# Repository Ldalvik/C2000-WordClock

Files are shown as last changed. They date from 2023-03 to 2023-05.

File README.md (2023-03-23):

# TI-F2806x-WordClock
A replication of my "RGB-WordClock" on a TI-C2000 F28069M, written in bare metal C.

## Software
Since there is no official HAL for this device, this project required deep digging into data sheets. I threw together a small library that does basic things like starting/stopping interrupts, interfacing the main loop to be more arduino-like, and all the other IO related things I would need like digital in/out and muxing. The most important part was setting the SPI peripheral to work with a real-time clock, specifically the DS1302. After reading the datasheet, I was able to get the correct settings (baud-rate, polarity/phase, etc) and communicate back and forth with the RTC. I created a full library for it to work with this F2806x as well.

# Hardware

For the PCB, I used KiCAD and made a shield for the F28069. The LEDs I decided on were extremely small (about a millimeter), and a microscope was needed to place them correctly. Other components consist of the DS1302, resistors for each LED, capacitor for filtering, 6pF 32.768khz crystal, and a small coin cell battery for a few days of time keeping while unplugged.

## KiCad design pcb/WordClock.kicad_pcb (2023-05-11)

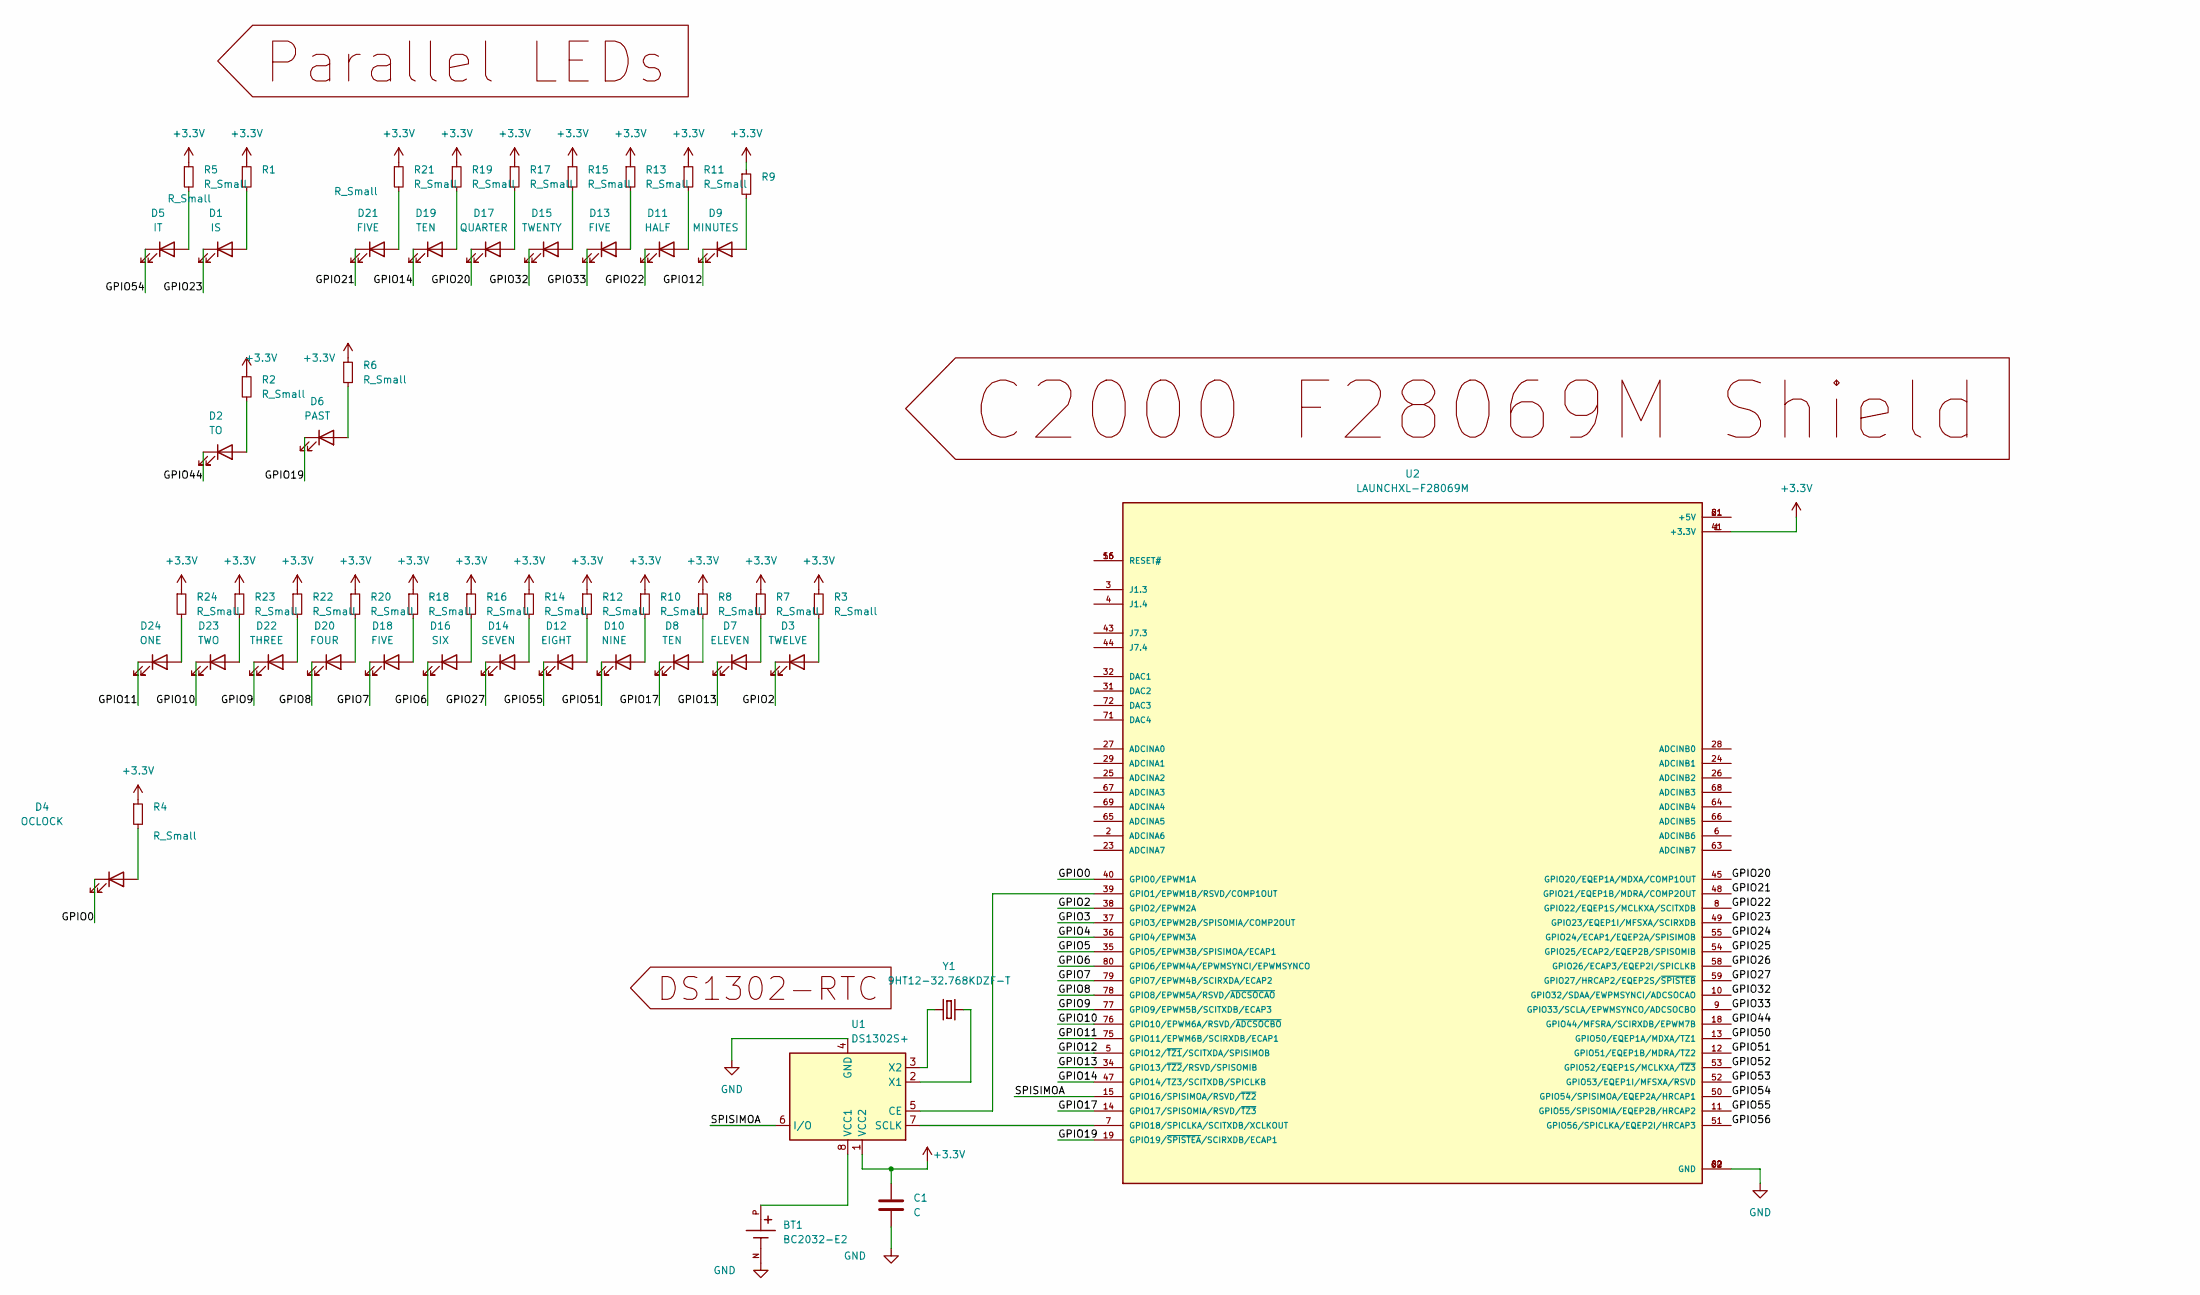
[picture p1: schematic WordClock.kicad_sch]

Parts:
BT1: BC2032-E2; MPD_BC2032-E2; PARTREV D
C1: C; C_0805_2012Metric
D1: IS; LED_0201_0603Metric_Pad0.64x0.40mm_HandSolder
D2: TO; LED_0201_0603Metric_Pad0.64x0.40mm_HandSolder
D3: TWELVE; LED_0201_0603Metric_Pad0.64x0.40mm_HandSolder
D4: OCLOCK; LED_0201_0603Metric_Pad0.64x0.40mm_HandSolder
D5: IT; LED_0201_0603Metric_Pad0.64x0.40mm_HandSolder
D6: PAST; LED_0201_0603Metric_Pad0.64x0.40mm_HandSolder
D7: ELEVEN; LED_0201_0603Metric_Pad0.64x0.40mm_HandSolder
D8, D19: TEN; LED_0201_0603Metric_Pad0.64x0.40mm_HandSolder
D9: MINUTES; LED_0201_0603Metric_Pad0.64x0.40mm_HandSolder
D10: NINE; LED_0201_0603Metric_Pad0.64x0.40mm_HandSolder
D11: HALF; LED_0201_0603Metric_Pad0.64x0.40mm_HandSolder
D12: EIGHT; LED_0201_0603Metric_Pad0.64x0.40mm_HandSolder
D13, D18, D21: FIVE; LED_0201_0603Metric_Pad0.64x0.40mm_HandSolder
D14: SEVEN; LED_0201_0603Metric_Pad0.64x0.40mm_HandSolder
D15: TWENTY; LED_0201_0603Metric_Pad0.64x0.40mm_HandSolder
D16: SIX; LED_0201_0603Metric_Pad0.64x0.40mm_HandSolder
D17: QUARTER; LED_0201_0603Metric_Pad0.64x0.40mm_HandSolder
D20: FOUR; LED_0201_0603Metric_Pad0.64x0.40mm_HandSolder
D22: THREE; LED_0201_0603Metric_Pad0.64x0.40mm_HandSolder
D23: TWO; LED_0201_0603Metric_Pad0.64x0.40mm_HandSolder
D24: ONE; LED_0201_0603Metric_Pad0.64x0.40mm_HandSolder
R1, R2, R3, R4, R5, R6, R7, R8, R9, R10, R11, R12, R13, R14, R15, R16, R17, R18, R19, R20, R21, R22, R23, R24: R_Small; R_0805_2012Metric_Pad1.20x1.40mm_HandSolder
U1: DS1302S+; SO-8_5.3x6.2mm_P1.27mm
U2: LAUNCHXL-F28069M; TI_LAUNCHXL-F28069M; PARTREV B
Y1: 9HT12-32.768KDZF-T; XTAL160X100X50

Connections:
+3.3V: C1.1, R1.1, R2.1, R3.1, R4.1, R5.1, R6.1, R7.1, R8.1, R9.1, R10.1, R11.1, R12.1, R13.1, R14.1, R15.1, R16.1, R17.1, R18.1, R19.1, R20.1, R21.1, R22.1, R23.1, R24.1, U1.1 (VCC2), U2.1 (+3.3V), U2.41 (+3.3V)
/GPIO0: D4.1 (K), U2.40 (GPIO0/EPWM1A)
/GPIO2: D3.1 (K), U2.38 (GPIO2/EPWM2A)
/GPIO3: U2.37 (GPIO3/EPWM2B/SPISOMIA/COMP2OUT)
/GPIO4: U2.36 (GPIO4/EPWM3A)
/GPIO5: U2.35 (GPIO5/EPWM3B/SPISIMOA/ECAP1)
/GPIO6: D16.1 (K), U2.80 (GPIO6/EPWM4A/EPWMSYNCI/EPWMSYNCO)
/GPIO7: D18.1 (K), U2.79 (GPIO7/EPWM4B/SCIRXDA/ECAP2)
/GPIO8: D20.1 (K), U2.78 (GPIO8/EPWM5A/RSVD/~ADCSOCAO)
/GPIO9: D22.1 (K), U2.77 (GPIO9/EPWM5B/SCITXDB/ECAP3)
/GPIO10: D23.1 (K), U2.76 (GPIO10/EPWM6A/RSVD/~ADCSOCBO)
/GPIO11: D24.1 (K), U2.75 (GPIO11/EPWM6B/SCIRXDB/ECAP1)
/GPIO12: D9.1 (K), U2.5 (GPIO12/~TZ1/SCITXDA/SPISIMOB)
/GPIO13: D7.1 (K), U2.34 (GPIO13/~TZ2/RSVD/SPISOMIB)
/GPIO14: D19.1 (K), U2.47 (GPIO14/TZ3/SCITXDB/SPICLKB)
/GPIO17: D8.1 (K), U2.14 (GPIO17/SPISOMIA/RSVD/~TZ3)
/GPIO19: D6.1 (K), U2.19 (GPIO19/~SPISTEA/SCIRXDB/ECAP1)
/GPIO20: D17.1 (K), U2.45 (GPIO20/EQEP1A/MDXA/COMP1OUT)
/GPIO21: D21.1 (K), U2.48 (GPIO21/EQEP1B/MDRA/COMP2OUT)
/GPIO22: D11.1 (K), U2.8 (GPIO22/EQEP1S/MCLKXA/SCITXDB)
/GPIO23: D1.1 (K), U2.49 (GPIO23/EQEP1I/MFSXA/SCIRXDB)
/GPIO24: U2.55 (GPIO24/ECAP1/EQEP2A/SPISIMOB)
/GPIO25: U2.54 (GPIO25/ECAP2/EQEP2B/SPISOMIB)
/GPIO26: U2.58 (GPIO26/ECAP3/EQEP2I/SPICLKB)
/GPIO27: D14.1 (K), U2.59 (GPIO27/HRCAP2/EQEP2S/~SPISTEB)
/GPIO32: D15.1 (K), U2.10 (GPIO32/SDAA/EWPMSYNCI/ADCSOCAO)
/GPIO33: D13.1 (K), U2.9 (GPIO33/SCLA/EPWMSYNCO/ADCSOCBO)
/GPIO44: D2.1 (K), U2.18 (GPIO44/MFSRA/SCIRXDB/EPWM7B)
/GPIO50: U2.13 (GPIO50/EQEP1A/MDXA/TZ1)
/GPIO51: D10.1 (K), U2.12 (GPIO51/EQEP1B/MDRA/TZ2)
/GPIO52: U2.53 (GPIO52/EQEP1S/MCLKXA/~TZ3)
/GPIO53: U2.52 (GPIO53/EQEP1I/MFSXA/RSVD)
/GPIO54: D5.1 (K), U2.50 (GPIO54/SPISIMOA/EQEP2A/HRCAP1)
/GPIO55: D12.1 (K), U2.11 (GPIO55/SPISOMIA/EQEP2B/HRCAP2)
/GPIO56: U2.51 (GPIO56/SPICLKA/EQEP2I/HRCAP3)
/SPISIMOA: U1.6 (I/O), U2.15 (GPIO16/SPISIMOA/RSVD/~TZ2)
GND: BT1.N, C1.2, U1.4 (GND), U2.22 (GND), U2.60 (GND), U2.62 (GND)
unnamed: BT1.P, U1.8 (VCC1)
unnamed: D1.2 (A), R1.2
unnamed: D2.2 (A), R2.2
unnamed: D3.2 (A), R3.2
unnamed: D4.2 (A), R4.2
unnamed: D5.2 (A), R5.2
unnamed: D6.2 (A), R6.2
unnamed: D7.2 (A), R7.2
unnamed: D8.2 (A), R8.2
unnamed: D9.2 (A), R9.2
unnamed: D10.2 (A), R10.2
unnamed: D11.2 (A), R11.2
unnamed: D12.2 (A), R12.2
unnamed: D13.2 (A), R13.2
unnamed: D14.2 (A), R14.2
unnamed: D15.2 (A), R15.2
unnamed: D16.2 (A), R16.2
unnamed: D17.2 (A), R17.2
unnamed: D18.2 (A), R18.2
unnamed: D19.2 (A), R19.2
unnamed: D20.2 (A), R20.2
unnamed: D21.2 (A), R21.2
unnamed: D22.2 (A), R22.2
unnamed: D23.2 (A), R23.2
unnamed: D24.2 (A), R24.2
unnamed: U1.2 (X1), Y1.2
unnamed: U1.3 (X2), Y1.1
unnamed: U1.5 (CE), U2.39 (GPIO1/EPWM1B/RSVD/COMP1OUT)
unnamed: U1.7 (SCLK), U2.7 (GPIO18/SPICLKA/SCITXDB/XCLKOUT)
unnamed: U2.16 (RESET#), U2.56 (RESET#)
unnamed: U2.21 (+5V), U2.61 (+5V)

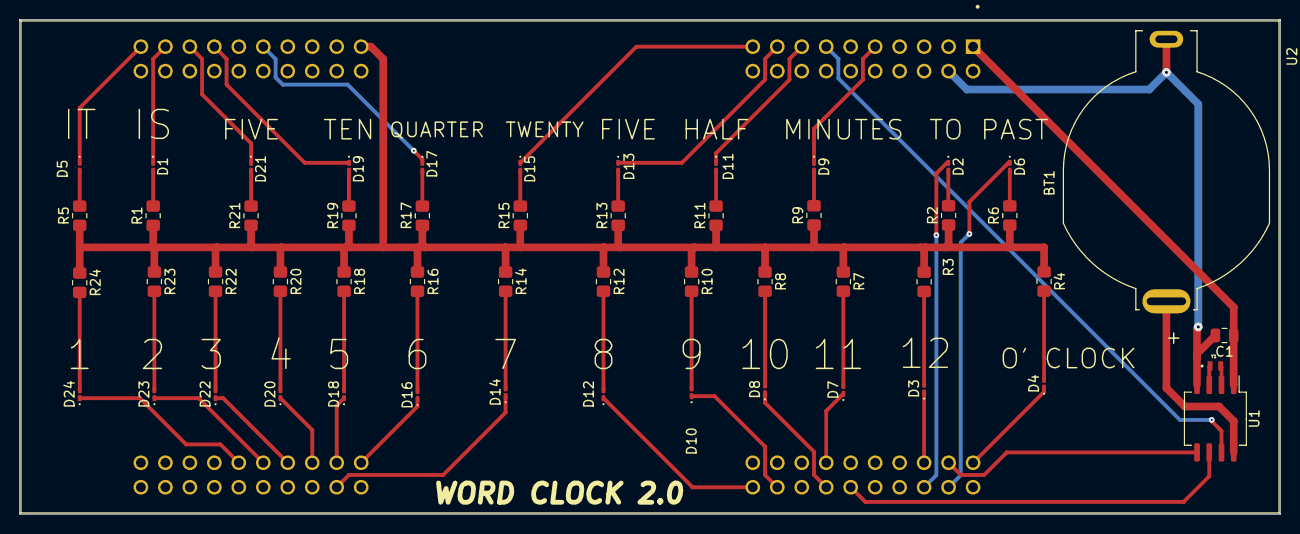
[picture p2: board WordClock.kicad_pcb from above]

Board: 2 copper layers, 130.8 x 51.3 mm, 53 parts (0 on the bottom side), 58 nets.

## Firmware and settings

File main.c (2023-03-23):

#include <libraries/DS1302.h>
#include <libraries/F28069M.h>
#include <libraries/wordclock.h>
#include <includes.h>

int HOUR   = 3;
int MINUTE = 59;
int SECOND = 50;
int DAY    = Tuesday;
int MONTH  = 12;
int DATE   = 10;
int YEAR   = 2022;

uint32_t RTC_BAUDRATE = (uint32_t) ((LSPCLK_HZ / 500000) - 1); // RTC Baudrate

uint16_t second, minute, hour, date, month, day, year = 0;

//int * words = {0,0,0};

void setup(void)
{
   /*  Initialize the SPI peripheral with the configuration needed to communicate
       with the DS1302 RTC. */

   /*  Commands are 8 bits long */

   /*  The baudrate is determined by the speed of the clock and the speed of the crystal.
    *  The F28069M has a low speed clock of 22,500,000 HZ. The crystal used for the DS1302 runs
    *  at 500,000 HZ while at the minimum voltage of 2v. 22,500,000 / 500,000 = 45.
    *  The baud rate must be set to a minimum of 45 - 1 = 44.
    */

    /* It receives data on the rising edge, and sends data back on the falling edge,
       so the clock cycle will be RISING EDGE WITH DELAY. */

    /* Data must be transmitted in MASTER_MODE */

    /* The DS1302 uses 3-wire SPI (chip select, data, clock) to send and
     * receive data between itself and the controller, so enabling TRIWIRE
     * mode will save you an extra pin.
     */

    SpiA_Init(8,              // Char length = 8
              RTC_BAUDRATE,   // Baudrate = (22,500,000 / 500,000) - 1 = 44
              RISING_EDGE,    // Rising edge
              W_DELAY,        // Delayed
              MASTER_MODE,    // Master mode
              TRIWIRE_MODE);  // Tri-wire mode

    DS1302_Init();

    pinMode(13, INPUT);

    if(digitalRead(13)){ // Set time ONLY when pin reads HIGH
        DS1302_setTime(HOUR, MINUTE, SECOND, DATE, MONTH, DAY, YEAR);
    }

    WordClock_Init();


    WordClock_CheckLEDS();
    //WordClock_CheckTime(4);
}

void loop(void)
{

    int *time = DS1302_getTime();

    second = time[0];
    minute = time[1];
    hour   = time[2];
    date   = time[3];
    month  = time[4];
    day    = time[5];
    year   = time[6];

    WordClock_setWordPins(hour, minute, second);
}

void main(void)
{
    DeviceSetup(setup, loop);
}

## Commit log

2023-03-23 Add project libraries + F28069 drivers to GitHub
2023-03-23 Add TI F2806x driver header files
2023-03-23 Add TI F2806x driver source files
2023-05-11 Added PCB layouts
    [WordClock.kicad_pcb, WordClock.kicad_sch]
